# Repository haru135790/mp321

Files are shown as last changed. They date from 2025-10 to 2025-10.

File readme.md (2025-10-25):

# mp321-mpみつい

## 概要
mp321は、コンパクトな左手デバイスです。名刺サイズの基板に６つのキーとロータリーエンコーダーが搭載されています。
vialを使用してキー割り当てを自由に変更できます。

## 準備物
- mp321本体
- USBケーブル(AtoCまたはCtoC)
注意点：USBケーブルは通信ができるものを使用してください。100均等で「充電専用」として販売されているものは使用出来ません。

## キー割り当ての変更
本機のキー割り当ては「[vial](https://get.vial.today)」というソフトウェアを使用することで変更できます。
vialにはwebブラウザ版とアプリケーション版があり、ブラウザ版はChrome、アプリ版はWindows,macOS,Linuxで動作します。
また、2025/10/21時点で、vialは日本語対応していません。ご注意ください。

ここでは、vialを使用するとできることについて簡単に説明します。(詳細な操作方法等についてはネットで検索するか、後述の参考記事をご覧ください)
1. キーマップの変更
   - キーに割り当てられた機能を自由に変更できます。
   - キーボードに実際にあるキーだけでなく、メディアキー(音楽の再生/停止など)や、特殊キー(画面の明るさ調整など)も割り当て可能です。
   - 複数のキーを同時に押すショートカット(例: Ctrl+C)も一つのキーに割り当てられます。
2. マクロの設定
   - 複数のキー操作を一つのキーにまとめて割り当てることができます。
   - 例えば、「Ctrl+Aで全選択したあとに、Ctrl+Cでコピーする」といった連続した動作を一つのキーに設定することが可能です。
   - テキストの入力(「Hello, World!」と入力するなど)もマクロに含めることができます。
3. レイヤー機能
   - 複数のキーマップを作成し、特定のキーを押すことでキーマップを切り替えることができます。
   - 例えば、通常のキーマップと、ゲーム用のキーマップを切り替えることが可能です。
4. コンボキー
   - 複数のキーを同時に押すことで、別の機能を発動させることができます。
   - 例えば、AキーとBキーを同時に押すとCキーの機能が発動するように設定できます。
5. タップダンス
   - キーの押し方(単押し、長押し、単押し2回、単押しした直後に長押し)によって、異なる機能を割り当てることができます。
   - 例えば、普通にAキーを押すとAキーの機能が発動し、長押しするとBキーの機能が発動するように設定できます。

## 参考記事
vialの詳細な使用方法については、こちらの記事がおすすめです。
- [【初心者向け】Vialでキーボードをカスタムしよう！](https://alektor.hatenablog.com/entry/2024/11/15/233435)
- [（初心者編）Vialを使ってキーマップを書き換えよう-自作キーボード温泉街の歩き方](https://salicylic-acid3.hatenablog.com/entry/vial-manual)

## デフォルトキーマップ
mp321は初期状態では次のようなキー設定となっています。

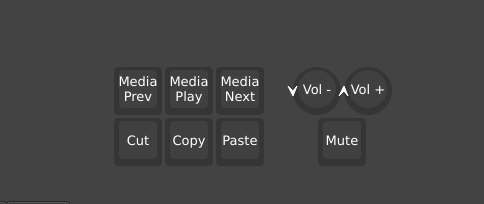
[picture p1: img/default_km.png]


mp321についているノブ(ロータリーエンコーダー)は、vial上では右回転と左回転、押し込みがそれぞれ分かれて表示されています。

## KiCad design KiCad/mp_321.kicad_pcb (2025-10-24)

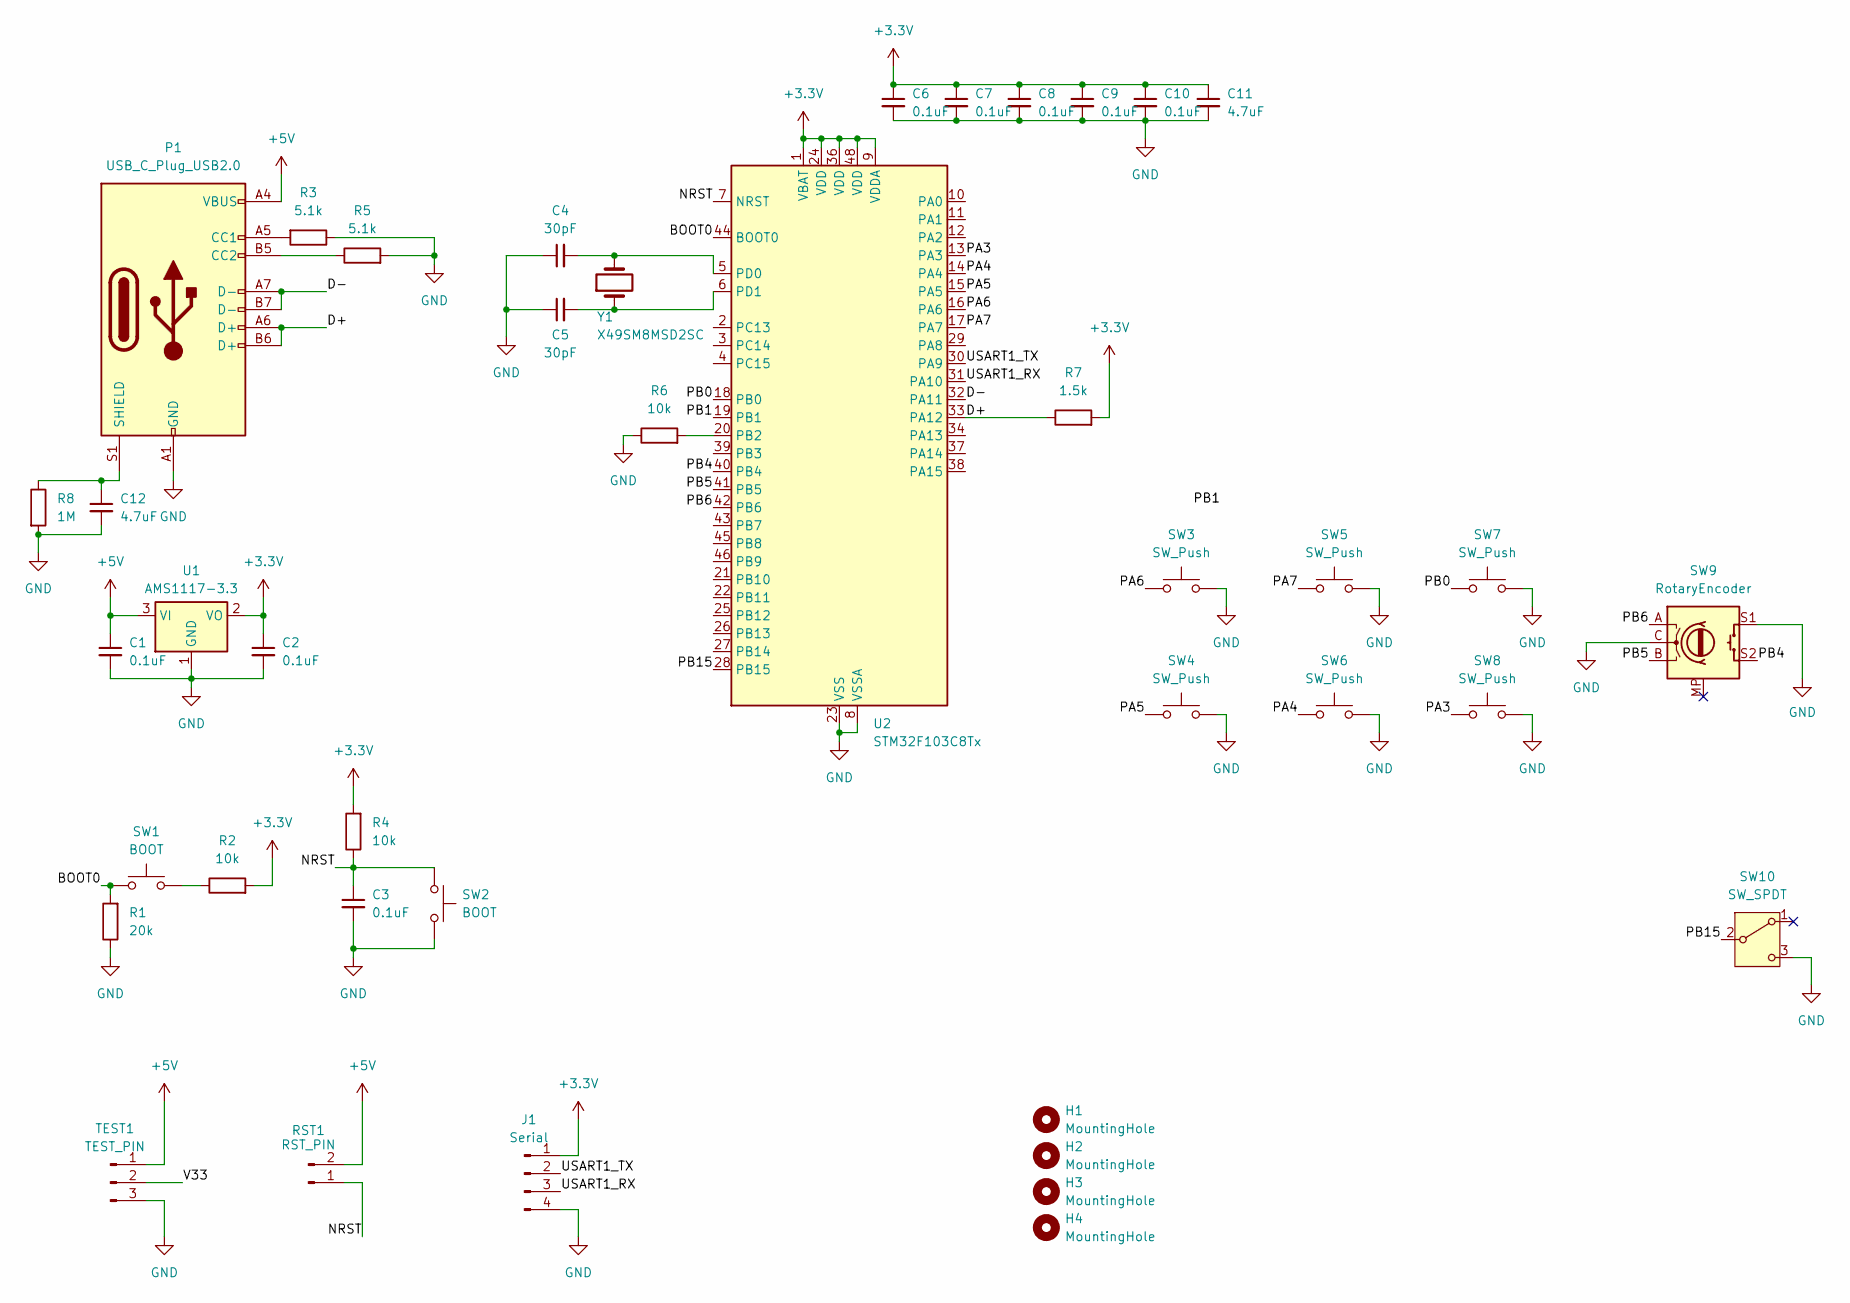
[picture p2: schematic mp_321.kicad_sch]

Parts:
C1, C2, C3, C6, C7, C8, C9, C10: 0.1uF; C_0603_1608Metric
C4, C5: 30pF; C_0603_1608Metric
C11, C12: 4.7uF; C_0603_1608Metric
H1, H2, H3, H4: MountingHole; MountingHole_3.2mm_M3
J1: Serial; PinHeader_1x04_P2.54mm_Vertical
P1: USB_C_Plug_USB2.0; USB_C_Receptacle_GCT_USB4105-xx-A_16P_TopMnt_Horizontal
R1: 20k; R_0603_1608Metric
R2, R4, R6: 10k; R_0603_1608Metric
R3, R5: 5.1k; R_0603_1608Metric
R7: 1.5k; R_0603_1608Metric
R8: 1M; R_0603_1608Metric
RST1: RST_PIN; TestPoint_2Pads_Pitch2.54mm_Drill0.8mm
SW1, SW2: BOOT; SW_Push_1P1T_XKB_TS-1187A
SW3, SW4, SW5, SW6, SW7, SW8: SW_Push; SW_Cherry_MX_PCB_1.00u
SW9: RotaryEncoder; RotaryEncoder_Alps_EC11E-Switch_Vertical_H20mm
SW10: SW_SPDT; SW_Push_1P1T-MP_NO_Horizontal_Alps_SSAJ120100
TEST1: TEST_PIN; PinSocket_1x03_P2.54mm_Vertical
U1: AMS1117-3.3; SOT-223-3_TabPin2
U2: STM32F103C8Tx; LQFP-48_7x7mm_P0.5mm
Y1: X49SM8MSD2SC; Crystal_SMD_HC49-SD

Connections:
+3.3V: C2.1, C6.1, C7.1, C8.1, C9.1, C10.1, C11.1, J1.1, R2.2, R4.2, R7.2, U1.2 (VO), U2.1 (VBAT), U2.9 (VDDA), U2.24 (VDD), U2.36 (VDD), U2.48 (VDD)
+5V: C1.1, P1.A4 (VBUS), P1.A9 (VBUS), P1.B4 (VBUS), P1.B9 (VBUS), RST1.2, TEST1.1, U1.3 (VI)
/BOOT0: R1.2, SW1.1, U2.44 (BOOT0)
/D+: P1.A6 (D+), P1.B6 (D+), R7.1, U2.33 (PA12)
/D-: P1.A7 (D-), P1.B7 (D-), U2.32 (PA11)
/NRST: C3.1, R4.1, RST1.1, SW2.1, U2.7 (NRST)
/PA3: SW8.1, U2.13 (PA3)
/PA4: SW6.1, U2.14 (PA4)
/PA5: SW4.1, U2.15 (PA5)
/PA6: SW3.1, U2.16 (PA6)
/PA7: SW5.1, U2.17 (PA7)
/PB0: SW7.1, U2.18 (PB0)
/PB1: U2.19 (PB1)
/PB4: SW9.S2, U2.40 (PB4)
/PB5: SW9.B, U2.41 (PB5)
/PB6: SW9.A, U2.42 (PB6)
/PB15: SW10.2 (B), U2.28 (PB15)
/USART1_RX: J1.3, U2.31 (PA10)
/USART1_TX: J1.2, U2.30 (PA9)
GND: C1.2, C2.2, C3.2, C4.1, C5.1, C6.2, C7.2, C8.2, C9.2, C10.2, C11.2, C12.2, J1.4, P1.A1 (GND), P1.A12 (GND), P1.B1 (GND), P1.B12 (GND), R1.1, R3.1, R5.2, R6.1, R8.2, SW2.2, SW3.2, SW4.2, SW5.2, SW6.2, SW7.2, SW8.2, SW9.C, SW9.S1, SW10.3 (C), TEST1.3, U1.1 (GND), U2.8 (VSSA), U2.23 (VSS), U2.35 (VSS), U2.47 (VSS)
unnamed: P1.A5 (CC1), R3.2
unnamed: P1.B5 (CC2), R5.1
unnamed: C12.1, P1.S1 (SHIELD), R8.1
unnamed: R2.1, SW1.2
unnamed: R6.2, U2.20 (PB2)
unnamed: C4.2, U2.5 (PD0), Y1.2
unnamed: C5.2, U2.6 (PD1), Y1.1

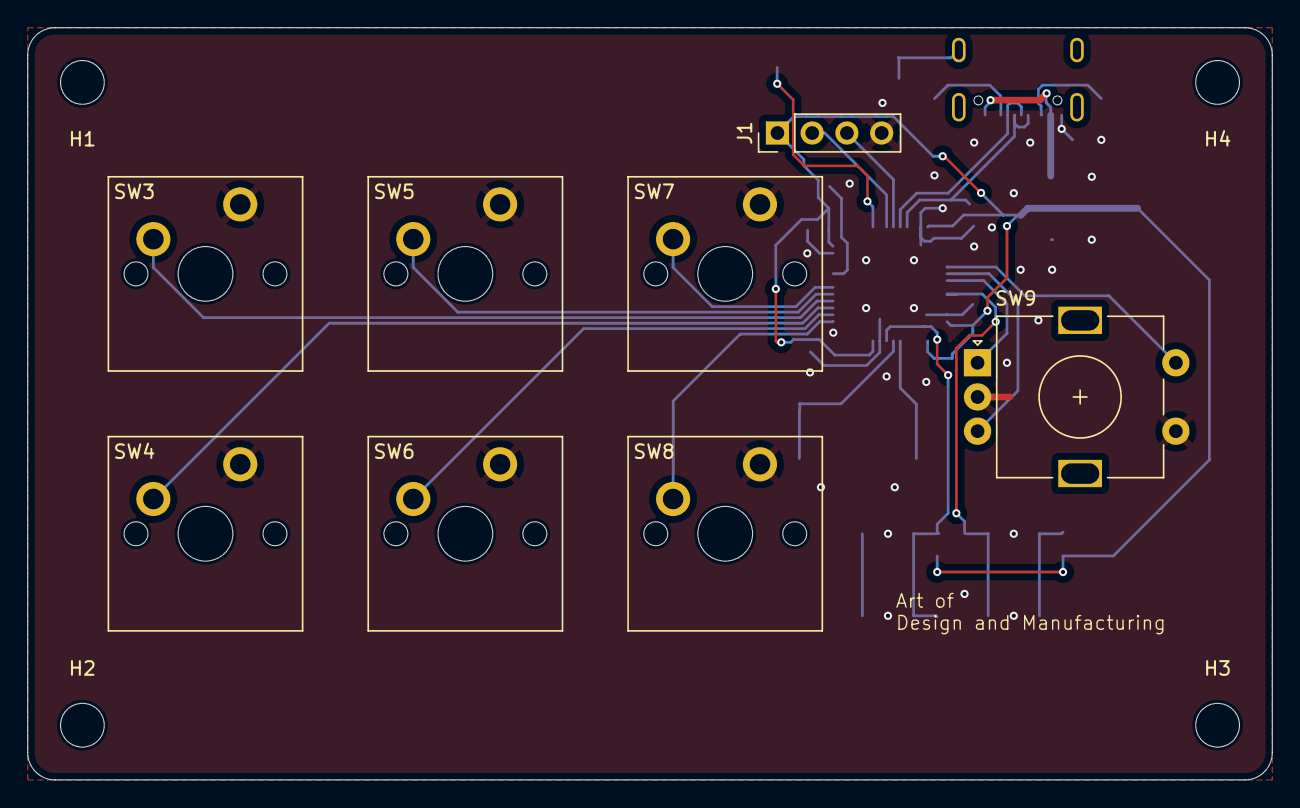
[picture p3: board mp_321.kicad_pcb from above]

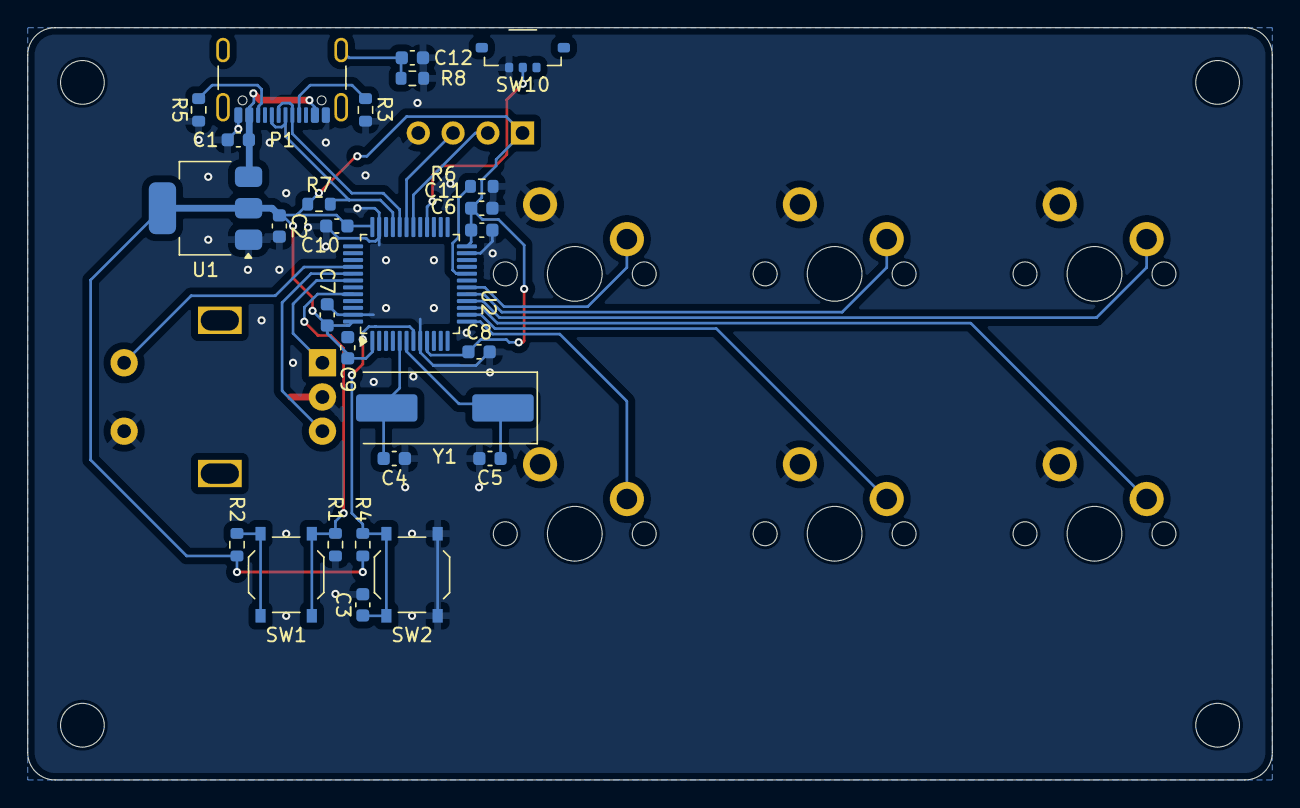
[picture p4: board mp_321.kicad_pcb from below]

Board: 2 copper layers, 91.0 x 55.0 mm, 39 parts (27 on the bottom side), 26 nets.

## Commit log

2025-10-24 デフォルトキーマップの画像を追加
2025-10-24 ディレクトリ構造を整理
    [mp_321.kicad_pcb, mp_321.kicad_sch]
2025-10-25 readme.mdのリンク切れを修正
2025-10-25 readme.md を更新
